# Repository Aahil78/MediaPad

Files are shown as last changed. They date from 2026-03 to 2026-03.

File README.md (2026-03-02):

 # MediaPad

MediaPad is an open-source, 3x4 macropad. It's powered by the Seeed Studio XIAO nRF52840 but can also be used with a Seeed Studio XIAO RP2040.

## Features:
  - 12 Hotswappable MX Switches
  - EC11 Rotary Encoder
  - Seeed Studio XIAO RP2040/nRF52840
  - (Optionable) Battery Support (Built in BMS on MCU)
  - ARGB Backlighting (SK6812-E)
  - Diodes to provide anti-ghosting
  - 3D Printed enclosure

## Images

### Schematic:
Schematic

### PCB:
PCB

### Case:
Case

### Full assembly:
Assembly

## BOM:

| Designator | Quantity | Value | Footprint | Package | MPN | DNP | Mount_Type | Description | PROD_ID | Voltage | Tolerance | Sim.Device | Sim.Pins |
|---|---|---|---|---|-----|-----|---|---|---|---|---|---|---|
| C1, C14 | 2 | 10uF | C_0402_1005Metric | | | | smt | Unpolarized capacitor | CAP-14848 | 6.3V | 20% | | |
| C10, C11, C12, C13, C2, C3, C4, C5, C6, C7, C8, C9 | 12 | 0.1uF | C_0402_1005Metric | | | | smt | Unpolarized capacitor | CAP-25565 | 16V | 10% | | |
| D10, D11, D12, D13, D2, D3, D4, D5, D6, D7, D8, D9 | 12 | D | D_0402_1005Metric | | | | smt | Diode | | | | D | 1=K 2=A  |
| LED10, LED11, LED12, LED13, LED2, LED3, LED4, LED5, LED6, LED7, LED8, LED9 | 12 | SK6812 | MX_SK6812MINI-E | | | | tht | RGB LED with integrated controller | | | | | |
| R1 | 1 | 330ohm | R_Axial_DIN0207_L6.3mm_D2.5mm_P10.16mm_Horizontal | | | | tht | 330Ω, 1/4W Resistor | | | | | |
| SW1 | 1 | RotaryEncoder_Switch_MP | RotaryEncoder_Alps_EC11E-Switch_Vertical_H20mm | | | | tht | Rotary encoder, dual channel, incremental quadrate outputs, with switch and MP Pin | | | | | |
| SW10, SW11, SW12, SW13, SW2, SW3, SW4, SW5, SW6, SW7, SW8, SW9 | 12 | SW_Push | SW_Hotswap_Kailh_Choc_V1 | | | | smt | Push button switch, generic, two pins | | | | | |
| U1 | 1 | XIAO-nRF52840-DIP | XIAO-nRF52840-DIP | | | | smt | | | | | | |
| U2 | 1 | SN74AHCT125DR | SOIC127P600X175-14N | | | | smt | | | | | | |

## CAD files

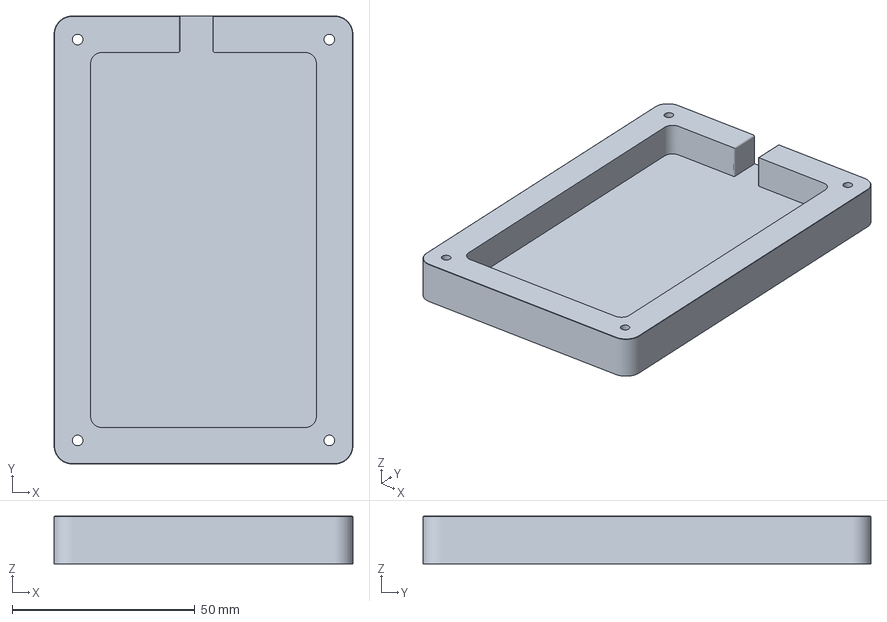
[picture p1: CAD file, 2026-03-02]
CAD/Base.3mf
81.7 x 122.5 x 13.0 mm

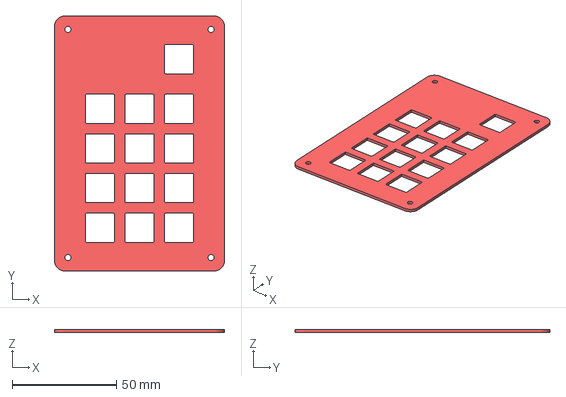
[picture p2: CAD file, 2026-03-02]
CAD/Plate.3mf
81.7 x 122.5 x 1.50 mm

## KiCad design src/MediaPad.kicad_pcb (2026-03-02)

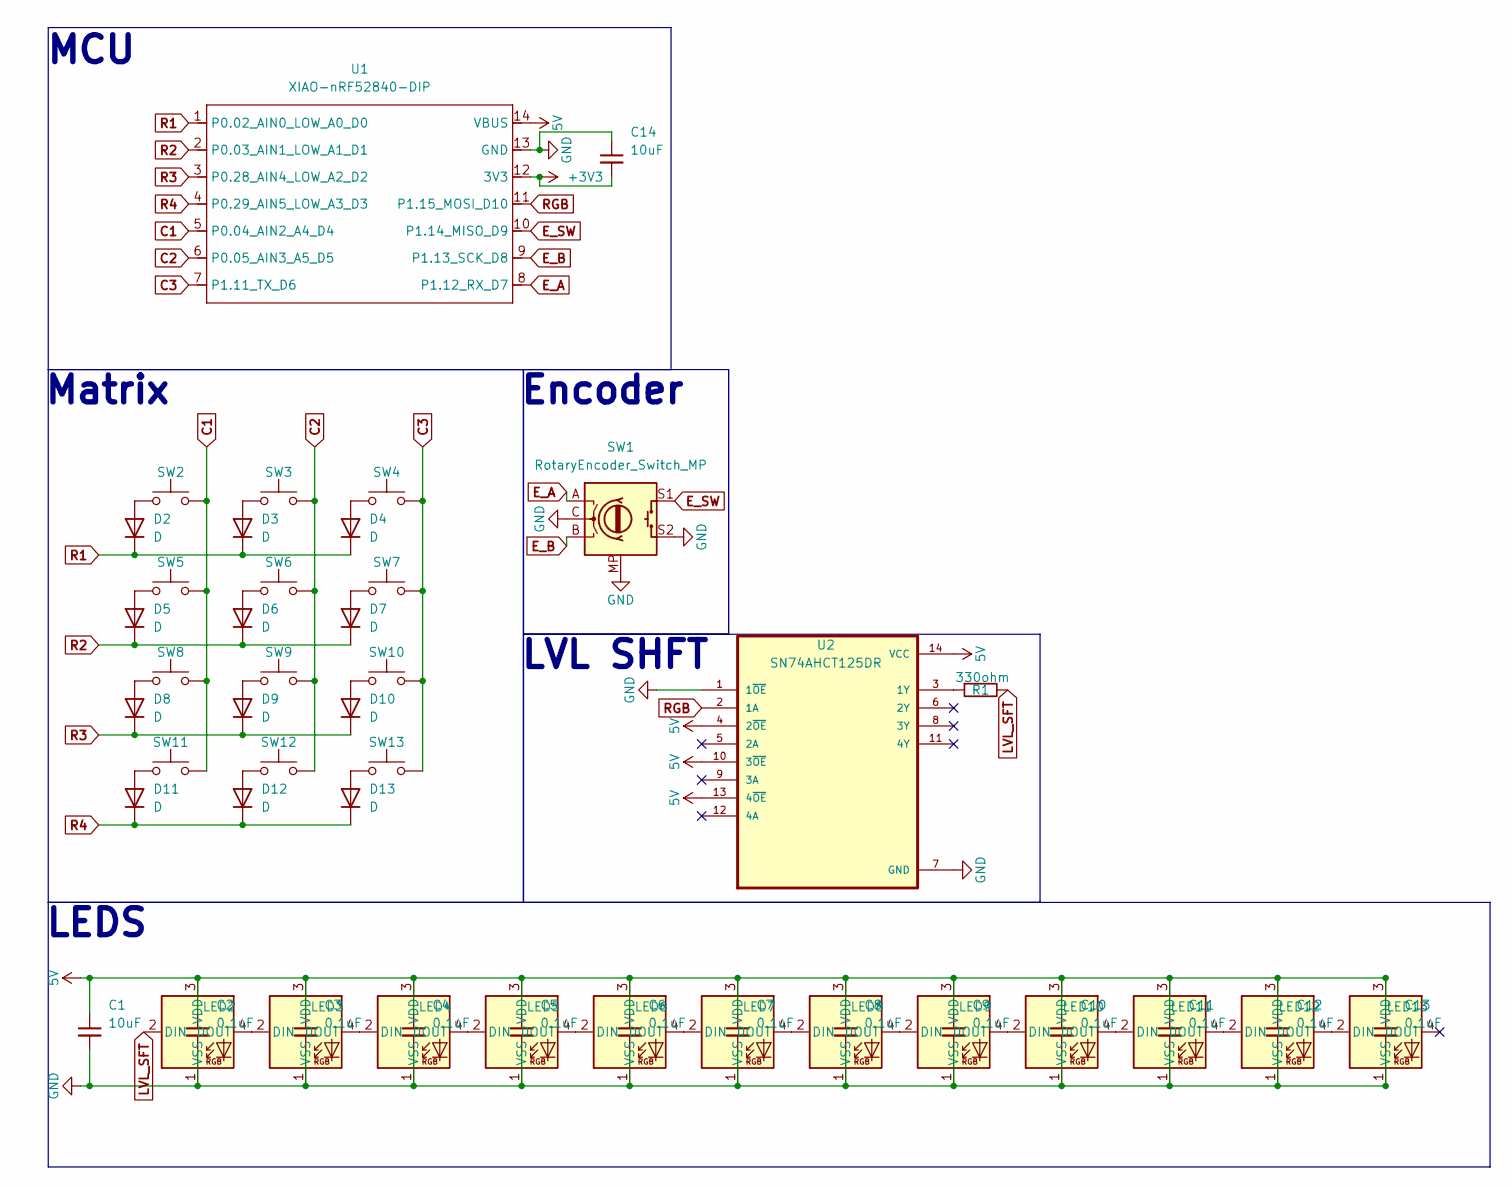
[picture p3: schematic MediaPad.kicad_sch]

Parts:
C1, C14: 10uF; C_0402_1005Metric; Voltage 6.3V; Tolerance 20%
C2, C3, C4, C5, C6, C7, C8, C9, C10, C11, C12, C13: 0.1uF; C_0402_1005Metric; Voltage 16V; Tolerance 10%
D2, D3, D4, D5, D6, D7, D8, D9, D10, D11, D12, D13: D; D_0402_1005Metric
LED2, LED3, LED4, LED5, LED6, LED7, LED8, LED9, LED10, LED11, LED12, LED13: SK6812; MX_SK6812MINI-E
R1: 330ohm; R_Axial_DIN0207_L6.3mm_D2.5mm_P10.16mm_Horizontal
SW1: RotaryEncoder_Switch_MP; RotaryEncoder_Alps_EC11E-Switch_Vertical_H20mm
SW2, SW3, SW4, SW5, SW6, SW7, SW8, SW9, SW10, SW11, SW12, SW13: SW_Push; SW_Hotswap_Kailh_Choc_V1
U1: XIAO-nRF52840-DIP
U2: SN74AHCT125DR; SOIC127P600X175-14N

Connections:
5V: C1.1, C2.1, C3.1, C4.1, C5.1, C6.1, C7.1, C8.1, C9.1, C10.1, C11.1, C12.1, C13.1, LED2.3 (VDD), LED3.3 (VDD), LED4.3 (VDD), LED5.3 (VDD), LED6.3 (VDD), LED7.3 (VDD), LED8.3 (VDD), LED9.3 (VDD), LED10.3 (VDD), LED11.3 (VDD), LED12.3 (VDD), LED13.3 (VDD), U1.14 (VBUS), U2.4 (2~OE), U2.10 (3~OE), U2.13 (4~OE), U2.14 (VCC)
+3V3: C14.2, U1.12 (3V3)
C1: SW2.2, SW5.2, SW8.2, SW11.2, U1.5 (P0.04_AIN2_A4_D4)
C2: SW3.2, SW6.2, SW9.2, SW12.2, U1.6 (P0.05_AIN3_A5_D5)
C3: SW4.2, SW7.2, SW10.2, SW13.2, U1.7 (P1.11_TX_D6)
E_A: SW1.A, U1.8 (P1.12_RX_D7)
E_B: SW1.B, U1.9 (P1.13_SCK_D8)
E_SW: SW1.S1, U1.10 (P1.14_MISO_D9)
GND: C1.2, C2.2, C3.2, C4.2, C5.2, C6.2, C7.2, C8.2, C9.2, C10.2, C11.2, C12.2, C13.2, C14.1, LED2.1 (VSS), LED3.1 (VSS), LED4.1 (VSS), LED5.1 (VSS), LED6.1 (VSS), LED7.1 (VSS), LED8.1 (VSS), LED9.1 (VSS), LED10.1 (VSS), LED11.1 (VSS), LED12.1 (VSS), LED13.1 (VSS), SW1.C, SW1.MP, SW1.S2, U1.13 (GND), U2.1 (1~OE), U2.7 (GND)
LVL_SFT: LED2.2 (DIN), R1.2
unnamed: D2.2 (A), SW2.1
unnamed: D3.2 (A), SW3.1
unnamed: D4.2 (A), SW4.1
unnamed: D5.2 (A), SW5.1
unnamed: D6.2 (A), SW6.1
unnamed: D7.2 (A), SW7.1
unnamed: D8.2 (A), SW8.1
unnamed: D9.2 (A), SW9.1
unnamed: D10.2 (A), SW10.1
unnamed: D11.2 (A), SW11.1
unnamed: D12.2 (A), SW12.1
unnamed: D13.2 (A), SW13.1
unnamed: LED2.4 (DOUT), LED3.2 (DIN)
unnamed: LED3.4 (DOUT), LED4.2 (DIN)
unnamed: LED4.4 (DOUT), LED5.2 (DIN)
unnamed: LED5.4 (DOUT), LED6.2 (DIN)
unnamed: LED6.4 (DOUT), LED7.2 (DIN)
unnamed: LED7.4 (DOUT), LED8.2 (DIN)
unnamed: LED8.4 (DOUT), LED9.2 (DIN)
unnamed: LED9.4 (DOUT), LED10.2 (DIN)
unnamed: LED10.4 (DOUT), LED11.2 (DIN)
unnamed: LED11.4 (DOUT), LED12.2 (DIN)
unnamed: LED12.4 (DOUT), LED13.2 (DIN)
unnamed: R1.1, U2.3 (1Y)
R1: D2.1 (K), D3.1 (K), D4.1 (K), U1.1 (P0.02_AIN0_LOW_A0_D0)
R2: D5.1 (K), D6.1 (K), D7.1 (K), U1.2 (P0.03_AIN1_LOW_A1_D1)
R3: D8.1 (K), D9.1 (K), D10.1 (K), U1.3 (P0.28_AIN4_LOW_A2_D2)
R4: D11.1 (K), D12.1 (K), D13.1 (K), U1.4 (P0.29_AIN5_LOW_A3_D3)
RGB: U1.11 (P1.15_MOSI_D10), U2.2 (1A)

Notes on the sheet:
Encoder
LEDS
MCU
LVL SHFT
Matrix

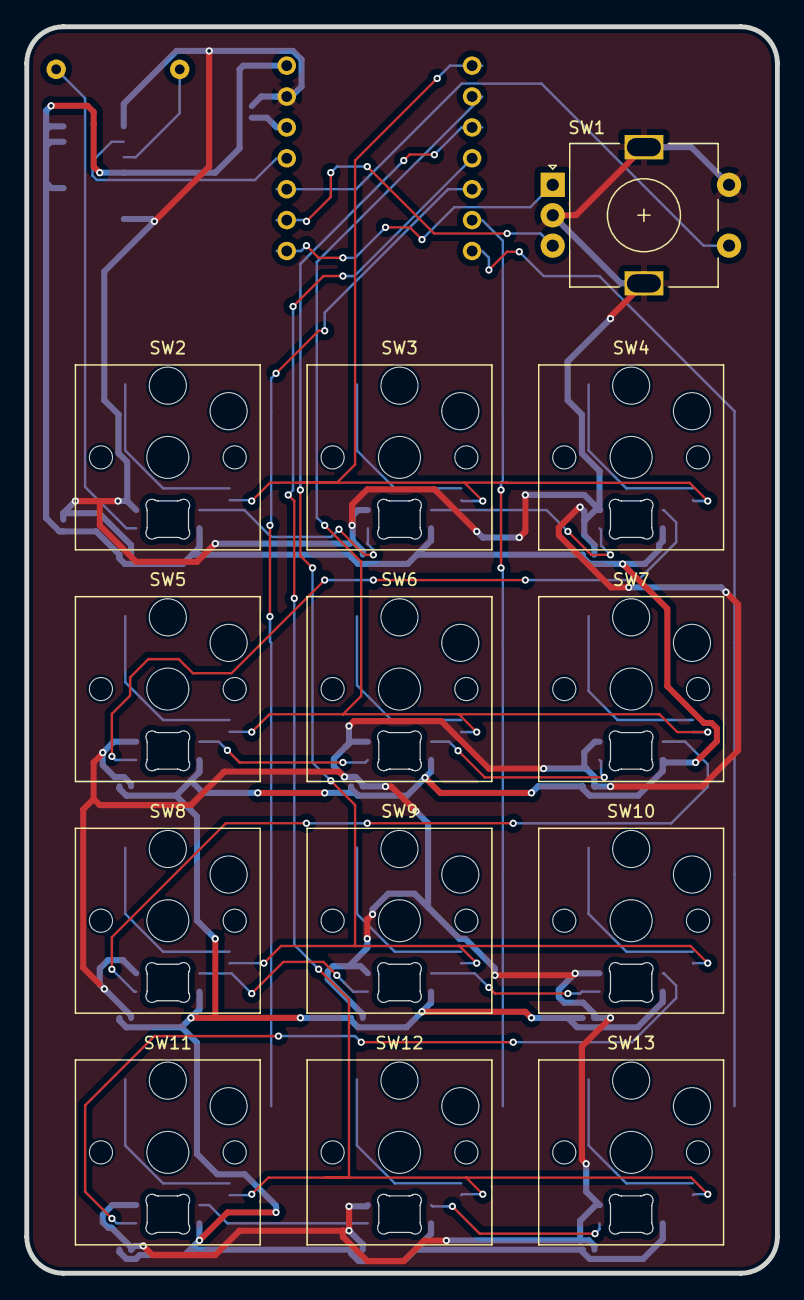
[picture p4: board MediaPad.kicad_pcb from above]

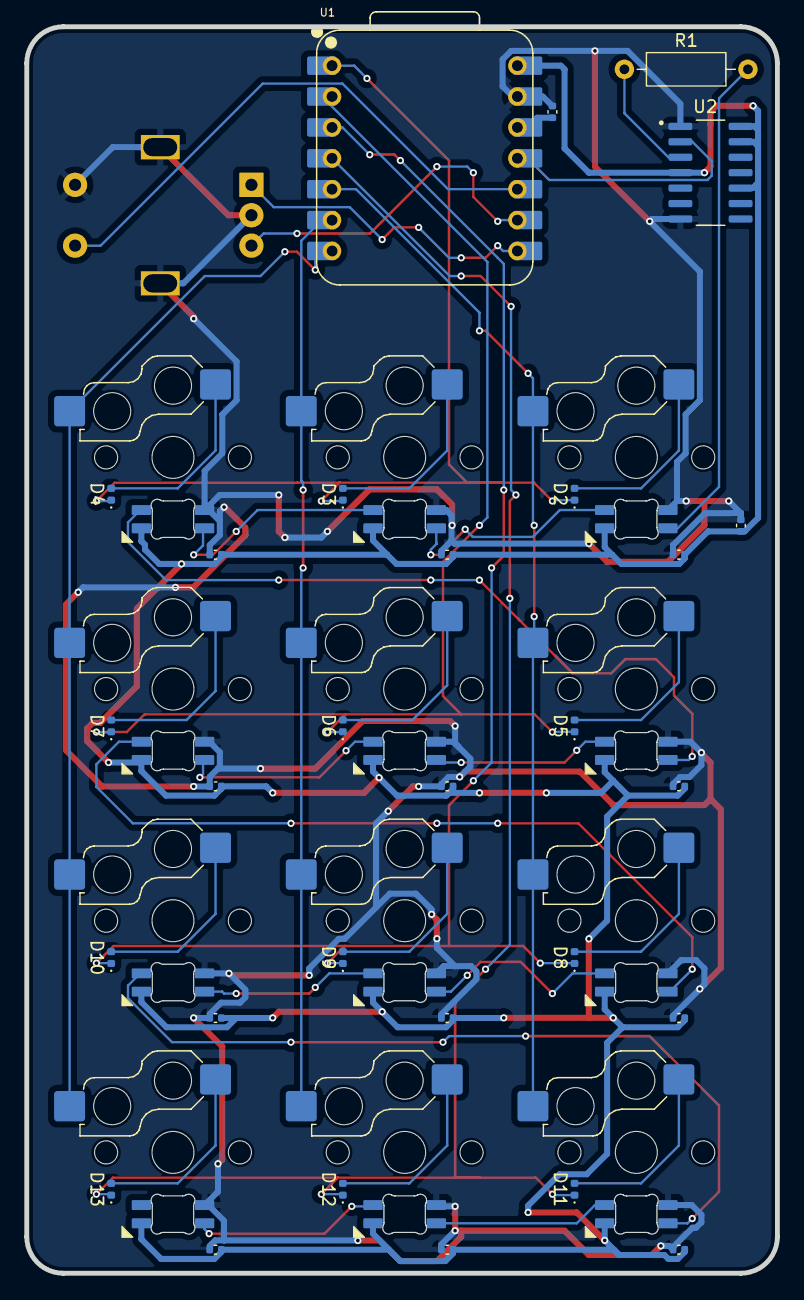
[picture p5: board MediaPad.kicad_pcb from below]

Board: 2 copper layers, 61.7 x 102.5 mm, 54 parts (29 on the bottom side), 39 nets.
